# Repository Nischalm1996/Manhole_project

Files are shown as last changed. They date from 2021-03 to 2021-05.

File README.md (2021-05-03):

# Manhole_project

## Pin Connection from Board 
| Pin Name  | Digital Pin |
|---|---|
|SCK | D13 |
| MOSI | D11 |
| OK | D6 |
| LEFT | D10 |
| RIGHT | D8 |
| RST | D12 |
| RED | D0 |
| GREEN | A6 |
| BLUE | A7 |
| MQ2 | A2 |
| MQ7 | A3 |
| MQ06 | A1 |
| MQ135 | A0 |

### MODULES USED
- DISPLAY 16x2 I2C
- SMOKE SENSOR (MQ02,MQ06,MQ07,MQ135)
- MQ02 (Methane, Butane, LPG, Hydrogen)
- MQ07 (CO, benzene)
- MQ06 (iso-butane, propane, LPG, LNG)
- MQ135 (NH3, NOx, alcohol,CO2)
- NAVIGATION BUTTON
- RGB LED
- GSM

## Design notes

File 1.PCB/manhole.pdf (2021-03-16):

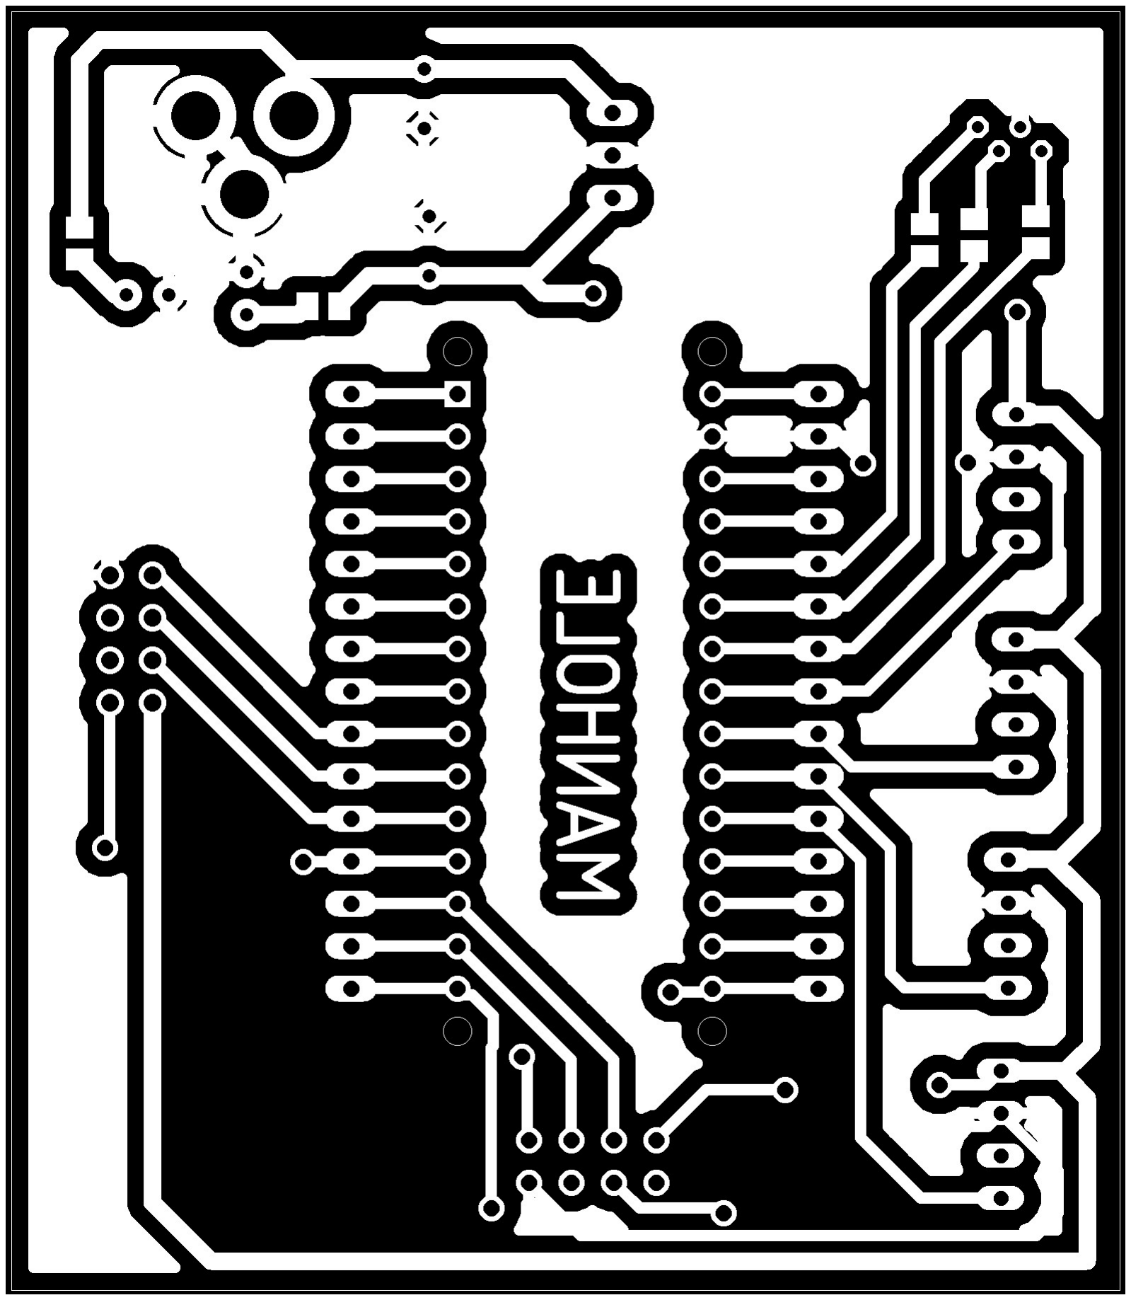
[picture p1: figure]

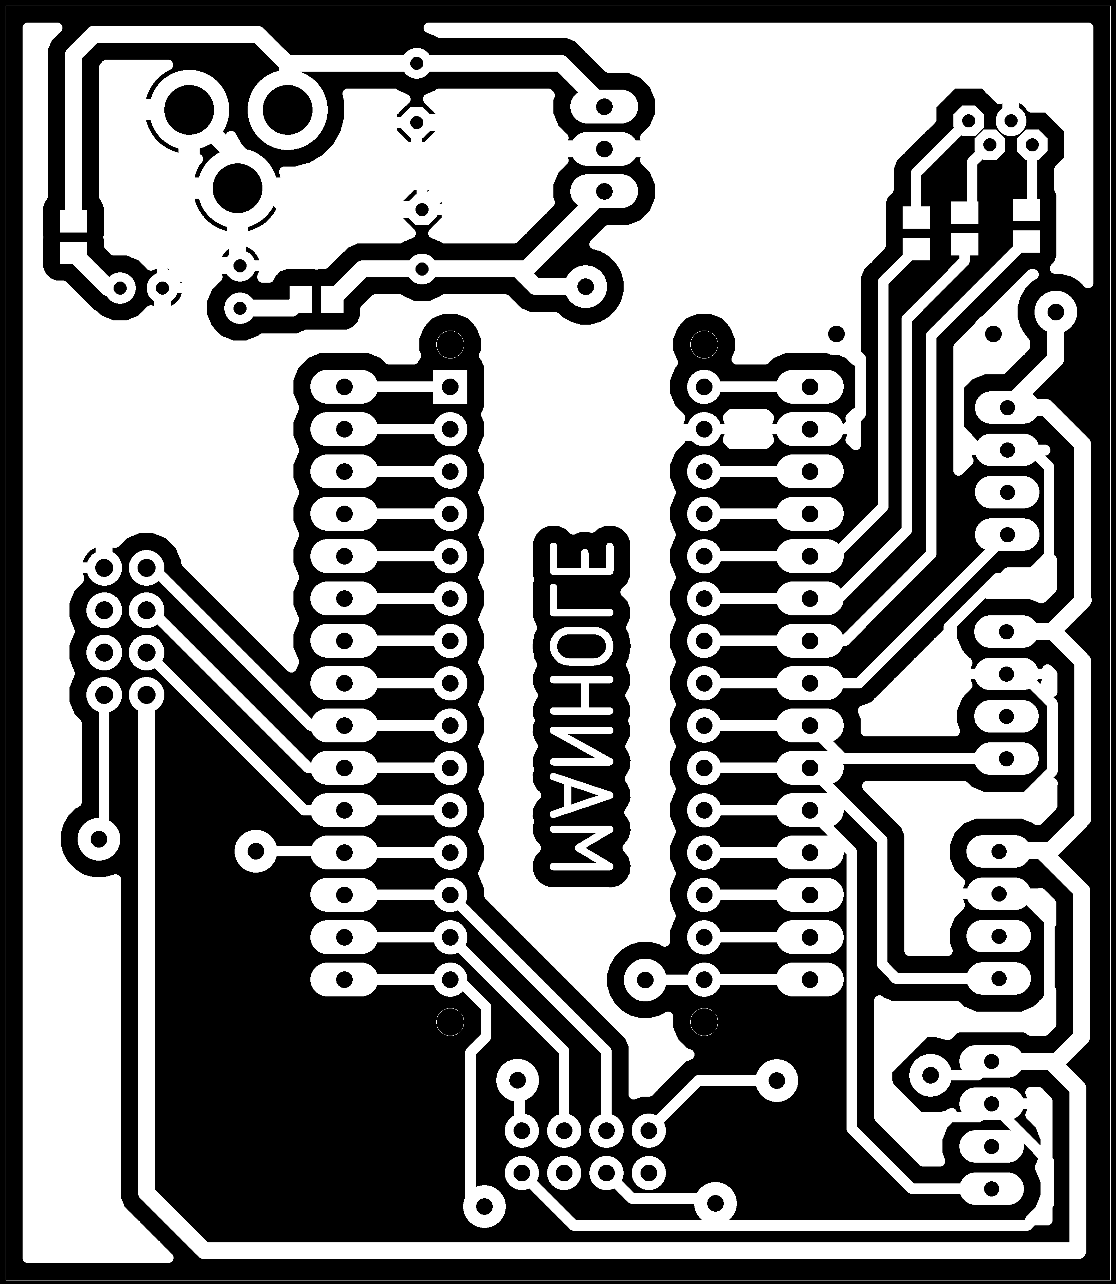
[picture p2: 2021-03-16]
1.PCB/manhole.png

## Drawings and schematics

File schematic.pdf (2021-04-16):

A

A

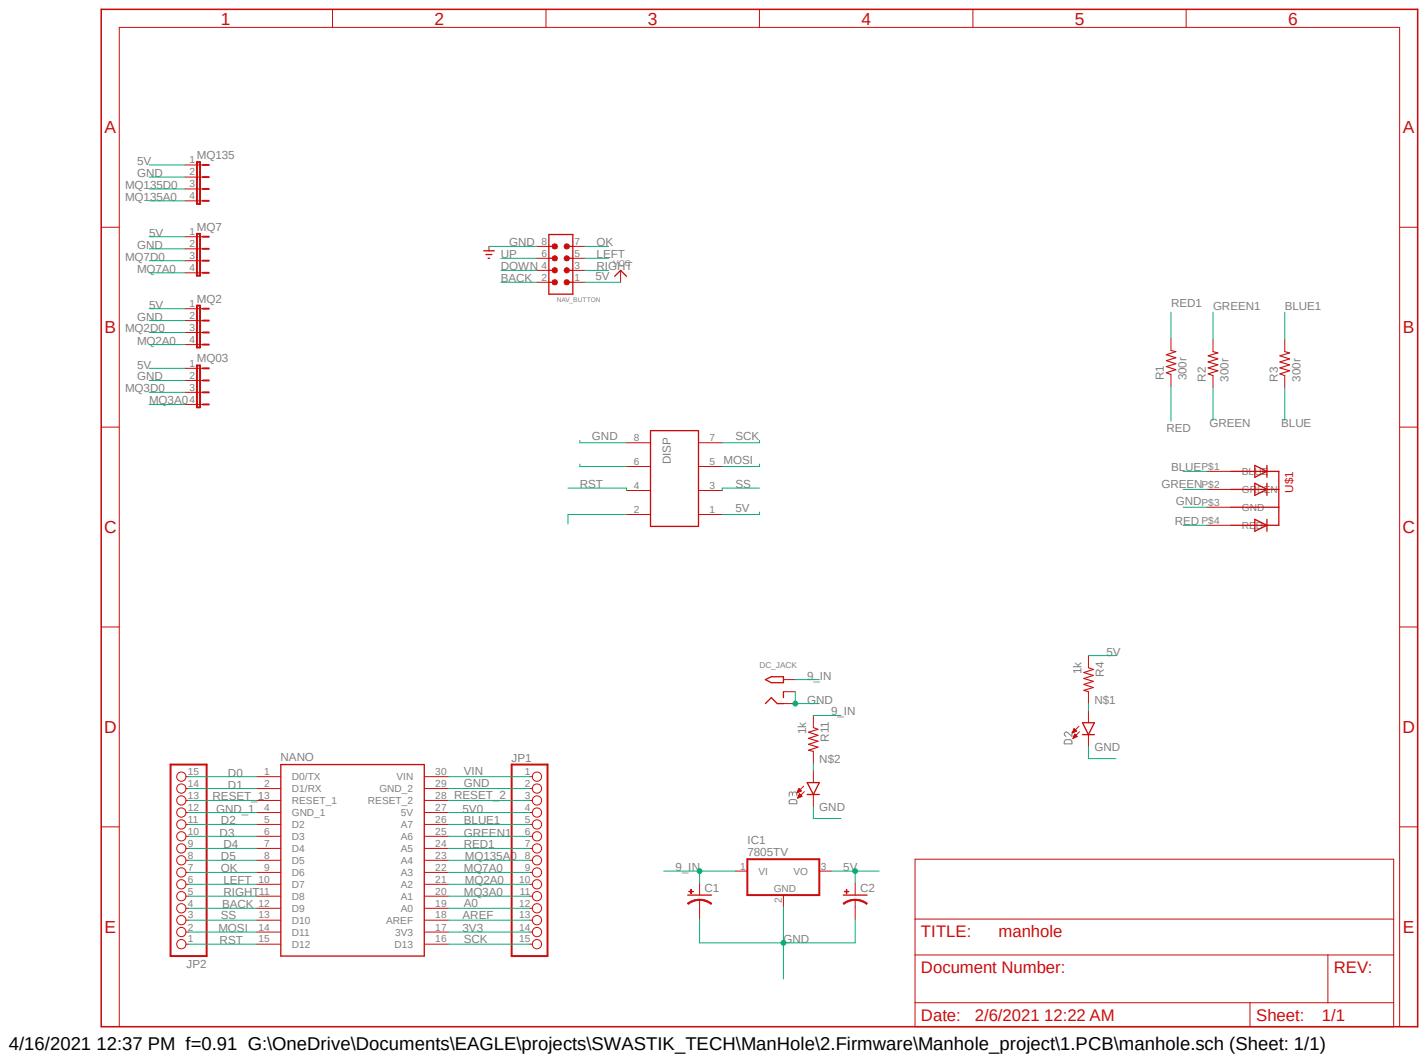
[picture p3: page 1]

Document Number: | REV:

Date: 2/6/2021 12:22 AM | Sheet: 1/1

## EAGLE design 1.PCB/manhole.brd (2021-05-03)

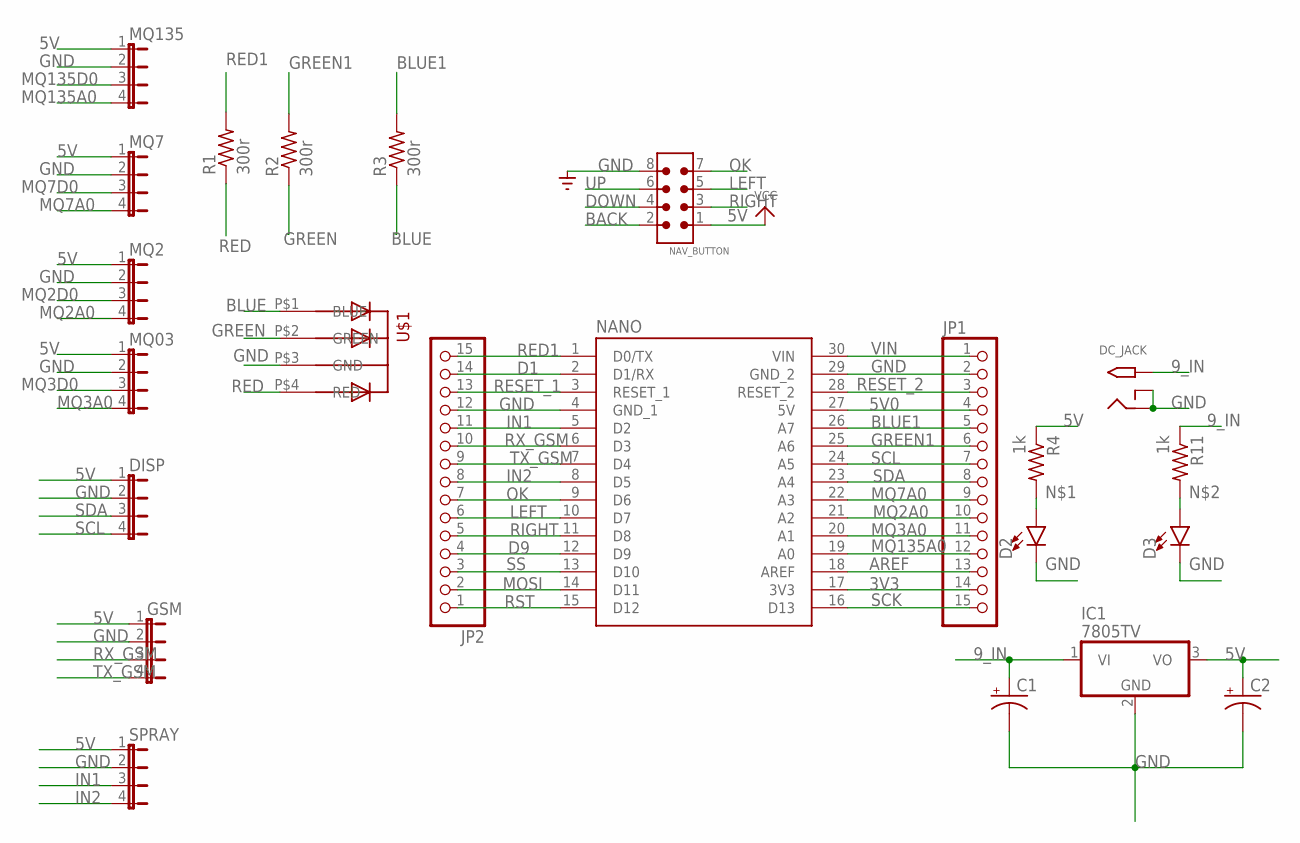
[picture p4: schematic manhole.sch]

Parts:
C1, C2: CPOL-USE3.5-8; E3,5-8
D2, D3: LED3MM; LED_3MM
DC_JACK: 2.1MMJACKTHM; PJ-102A
DISP: JP4E; JP4
GSM: JP4E; JP4
IC1: 7805TV; TO220V
JP1, JP2: PINHD-1X15; 1X15
MQ2, MQ03, MQ7, MQ135: JP4E; JP4
NANO: A000005; MODULE_A000005
NAV_BUTTON: 6120XX21621_61200821621; 61200821621
R1, R2, R3: 300r; M0805
R4, R11: 1k; M0805
SPRAY: JP4E; JP4
U$1: 5MMRGBLED; LED5MMRGB

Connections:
3V3: JP1.14, NANO.17 (3V3)
5V: C2.+, DISP.1, GSM.1, IC1.3 (VO), MQ2.1, MQ03.1, MQ7.1, MQ135.1, NAV_BUTTON.1, R4.1, SPRAY.1
5V0: JP1.4, NANO.27 (5V)
9_IN: C1.+, DC_JACK.TIP, IC1.1 (VI), R11.1
AREF: JP1.13, NANO.18 (AREF)
BACK: NAV_BUTTON.2
BLUE: R3.1, U$1.P$1 (BLUE)
BLUE1: JP1.5, NANO.26 (A7), R3.2
D1: JP2.14, NANO.2 (D1/RX)
D9: JP2.4, NANO.12 (D9)
DOWN: NAV_BUTTON.4
GND: C1.-, C2.-, D2.K (C), D3.K (C), DC_JACK.RING, DC_JACK.RING_SW, DISP.2, GSM.2, IC1.2 (GND), JP1.2, JP2.12, MQ2.2, MQ03.2, MQ7.2, MQ135.2, NANO.4 (GND_1), NANO.29 (GND_2), NAV_BUTTON.8, SPRAY.2, U$1.P$3 (GND)
GREEN: R2.1, U$1.P$2 (GREEN)
GREEN1: JP1.6, NANO.25 (A6), R2.2
IN1: JP2.11, NANO.5 (D2), SPRAY.3
IN2: JP2.8, NANO.8 (D5), SPRAY.4
LEFT: JP2.6, NANO.10 (D7), NAV_BUTTON.5
MOSI: JP2.2, NANO.14 (D11)
MQ2A0: JP1.10, MQ2.4, NANO.21 (A2)
MQ2D0: MQ2.3
MQ3A0: JP1.11, MQ03.4, NANO.20 (A1)
MQ3D0: MQ03.3
MQ7A0: JP1.9, MQ7.4, NANO.22 (A3)
MQ7D0: MQ7.3
MQ135A0: JP1.12, MQ135.4, NANO.19 (A0)
MQ135D0: MQ135.3
unnamed: D2.A, R4.2
unnamed: D3.A, R11.2
OK: JP2.7, NANO.9 (D6), NAV_BUTTON.7
RED: R1.1, U$1.P$4 (RED)
RED1: JP2.15, NANO.1 (D0/TX), R1.2
RESET_1: JP2.13, NANO.3 (RESET_1)
RESET_2: JP1.3, NANO.28 (RESET_2)
RIGHT: JP2.5, NANO.11 (D8), NAV_BUTTON.3
RST: JP2.1, NANO.15 (D12)
RX_GSM: GSM.3, JP2.10, NANO.6 (D3)
SCK: JP1.15, NANO.16 (D13)
SCL: DISP.4, JP1.7, NANO.24 (A5)
SDA: DISP.3, JP1.8, NANO.23 (A4)
SS: JP2.3, NANO.13 (D10)
TX_GSM: GSM.4, JP2.9, NANO.7 (D4)
UP: NAV_BUTTON.6
VIN: JP1.1, NANO.30 (VIN)

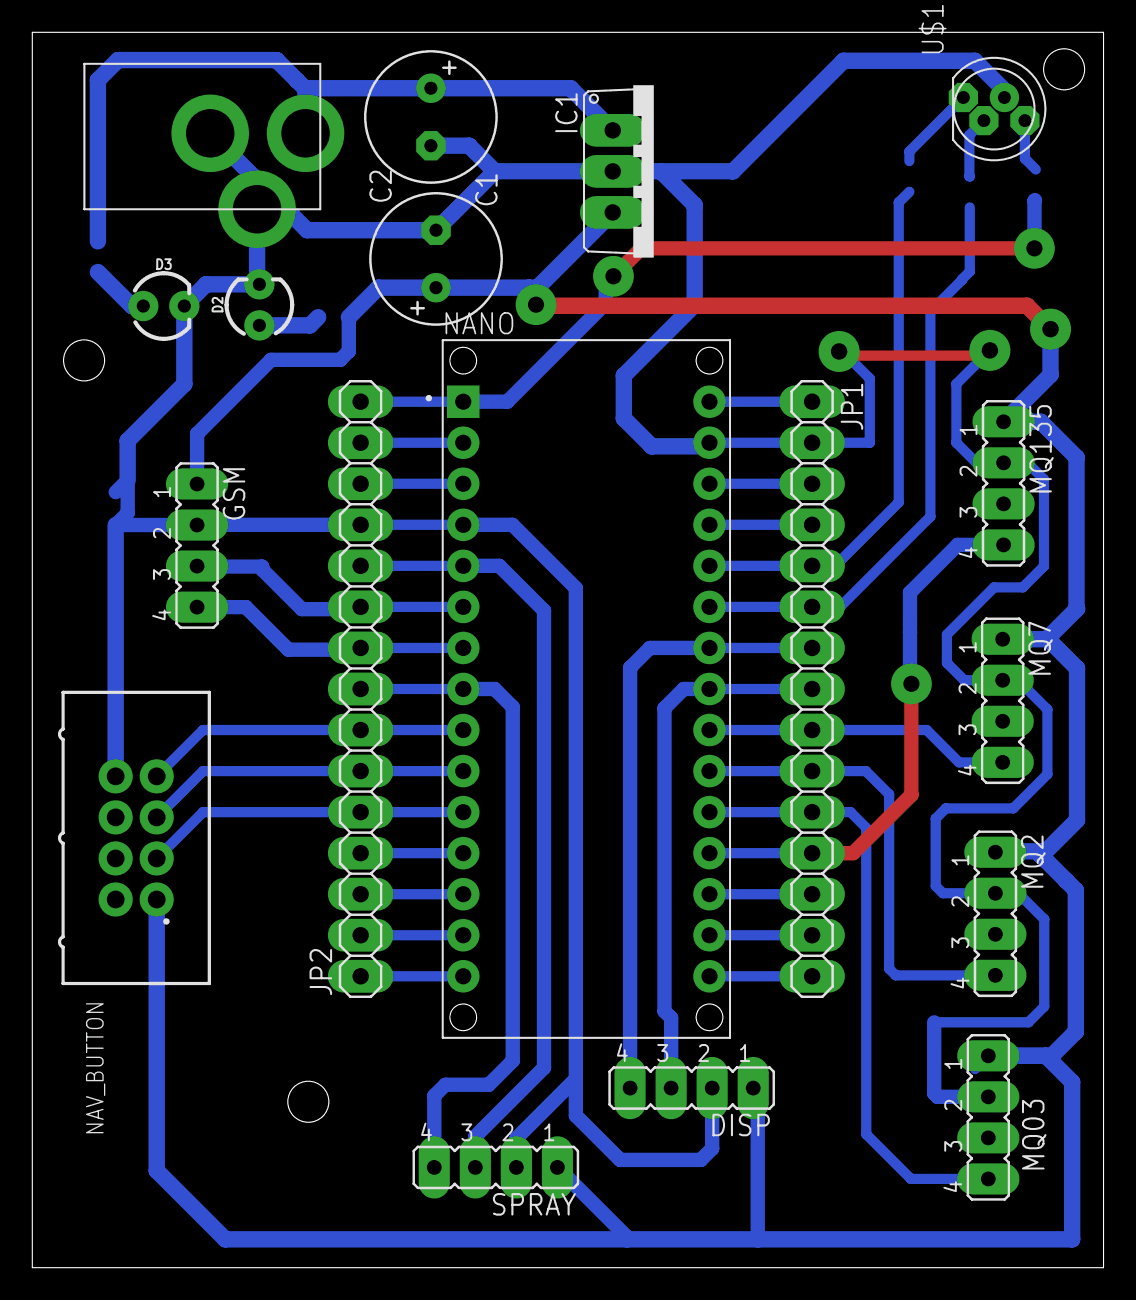
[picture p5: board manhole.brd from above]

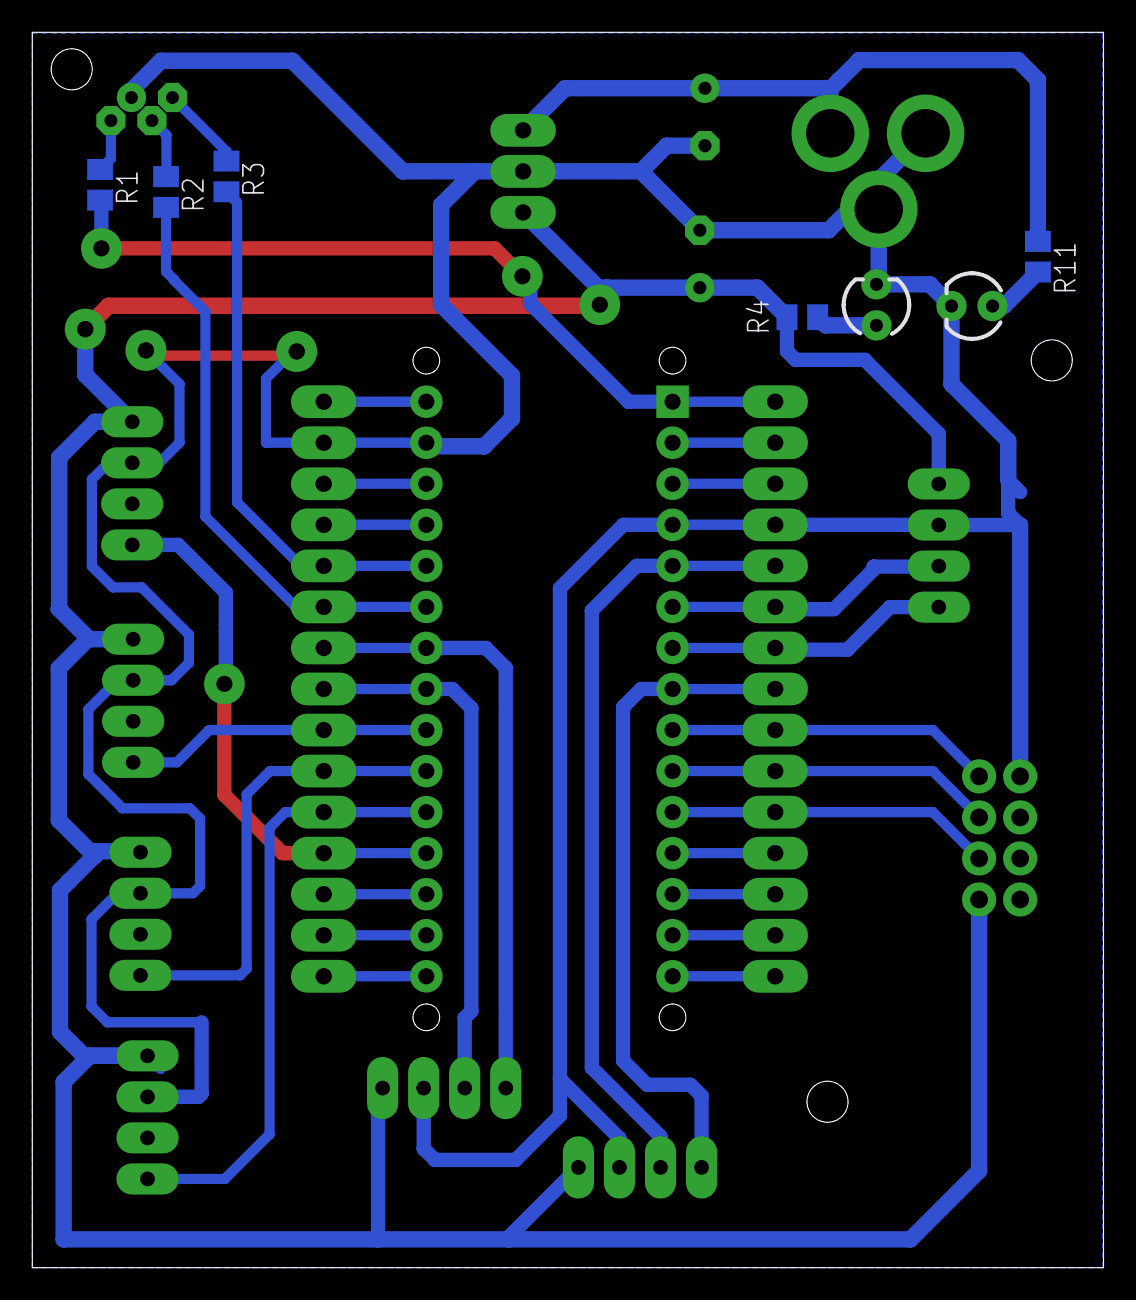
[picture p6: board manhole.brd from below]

Board: 2 copper layers, 66.3 x 76.5 mm, 23 parts (5 on the bottom side), 36 nets.

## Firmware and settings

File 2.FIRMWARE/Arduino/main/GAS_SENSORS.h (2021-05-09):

#ifndef _GAS_SENSOR_H
#define _GAS_SENSOR_H
#include "Arduino.h"
#include <MQUnifiedsensor.h>

/************************Hardware Related Macros************************************/
#define         Board                   ("Arduino Mega")
const int       PMQ135                  =(A0);
const int       PMQ7                    =(A1);
const int       PMQ6                    =(A2);
const int       PMQ2                    =(A3);
/***********************Software Related Macros************************************/
#define         RatioMQ2CleanAir          (9.83) //RS / R0 = 9.83 ppm 
#define         RatioMQ6CleanAir          (10) //RS / R0 = 10 ppm 
#define         RatioMQ7CleanAir          (27.5) //RS / R0 = 27.5 ppm  
#define         RatioMQ135CleanAir        (3.6) //RS / R0 = 9.6 ppm 
#define         ADC_Bit_Resolution        (10) // 10 bit ADC 
#define         Voltage_Resolution        (5) // Volt resolution to calc the voltage
#define         Type                      ("Arduino Nano") //Board used
/*****************************Globals***********************************************/
//Declare Sensor
MQUnifiedsensor MQ135(Board, Voltage_Resolution, ADC_Bit_Resolution, PMQ135, Type);
MQUnifiedsensor MQ2(Board, Voltage_Resolution, ADC_Bit_Resolution, PMQ2, Type);
MQUnifiedsensor MQ6(Board, Voltage_Resolution, ADC_Bit_Resolution, PMQ6, Type);
MQUnifiedsensor MQ7(Board, Voltage_Resolution, ADC_Bit_Resolution, PMQ7, Type);
class GAS_SENSORS
{
  public:
    void begin() {
      //Init serial port
      Serial.begin(9600);
      //init the sensor
      MQ2.init();
      MQ2.setRegressionMethod(1); //_PPM =  a*ratio^b
      MQ2.setA(574.25); MQ2.setB(-2.222); // Configurate the ecuation values to get LPG concentration
      MQ2.setR0(9.659574468);

      MQ6.init();
      MQ6.setRegressionMethod(1); //_PPM =  a*ratio^b
      MQ6.setA(2127.2); MQ6.setB(-2.526); // Configurate the ecuation values to get CH4 concentration
      MQ6.setR0(13.4285714);

      MQ7.init();
      MQ7.setRegressionMethod(1); //_PPM =  a*ratio^b
      MQ7.setA(99.042); MQ7.setB(-1.518); // Configurate the ecuation values to get CO concentration
      MQ7.setR0(4);

      MQ135.init();
      MQ135.setRegressionMethod(1); //_PPM =  a*ratio^b
      MQ135.setA(102.2); MQ135.setB(-2.473);// Configurate the ecuation values to get NH4 concentration
      MQ135.setR0(10);

      /*****************************  MQ CAlibration ********************************************/
      // Explanation:
      // In this routine the sensor will measure the resistance of the sensor supposing before was pre-heated
      // and now is on clean air (Calibration conditions), and it will setup R0 value.
      // We recomend execute this routine only on setup or on the laboratory and save on the eeprom of your arduino
      // This routine not need to execute to every restart, you can load your R0 if you know the value
      // Acknowledgements: https://jayconsystems.com/blog/understanding-a-gas-sensor
      Serial.print(F("Calibrating please wait."));
      float MQ2calcR0 = 0,
            MQ6calcR0 = 0,
            MQ7calcR0 = 0,
            MQ135calcR0 = 0;
      for (int i = 1; i <= 10; i ++)
      {
        //Update the voltage lectures
        MQ2.update();
        MQ6.update();
        MQ7.update();
        MQ135.update();

        MQ2calcR0 += MQ2.calibrate(RatioMQ2CleanAir);
        MQ6calcR0 += MQ2.calibrate(RatioMQ6CleanAir);
        MQ7calcR0 += MQ2.calibrate(RatioMQ7CleanAir);
        MQ135calcR0 += MQ2.calibrate(RatioMQ135CleanAir);
        Serial.print(F("."));
      }
      MQ2.setR0(MQ2calcR0 / 20);
      MQ6.setR0(MQ6calcR0 / 20);
      MQ7.setR0(MQ7calcR0 / 20);
      MQ135.setR0(MQ135calcR0 / 20);
      

      if (isinf(MQ2calcR0) || isinf(MQ6calcR0) || isinf(MQ7calcR0) || isinf(MQ135calcR0)) {
        Serial.println(F("Warning: Conection issue founded, R0 is infite (Open circuit detected) please check your wiring and supply"));
        while (1);
      }
      if (MQ2calcR0 == 0 || MQ6calcR0 == 0 || MQ7calcR0 == 0 || MQ135calcR0 == 0) {
        Serial.println(F("Warning: Conection issue founded, R0 is zero (Analog pin with short circuit to ground) please check your wiring and supply"));
        while (1);
      }
      /*****************************  MQ CAlibration ********************************************/
    }

    float getLpgPPM()
    {
      MQ2.update();
      return (MQ2.readSensor());
    }
    float getMethanePPM()
    {
      MQ6.update();
      return (MQ6.readSensor());
    }
    float getCoPPM()
    {
      MQ7.update();
      return (MQ7.readSensor());
    }
    float getAmmoniaPPM()
    {
      MQ135.update();
      return (MQ135.readSensor());
    }

};
#endif

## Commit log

2021-03-16 added PCB
    [manhole.brd, manhole.sch]
2021-03-16 PCB added
    [manhole.brd]
2021-04-16 added schematic
    [manhole.brd, manhole.sch]
2021-04-16 updated structure
    [manhole.brd, manhole.sch]
2021-04-17 SENSOR-MQ03,02,07,135 codes dumped
2021-04-17 added rgb led
2021-04-20 sensor pin updates
2021-04-21 MQ sensors gas detections
2021-04-28 edited button menu and gsm
2021-05-03 removed mq03 sensor
2021-05-04 updated PCB
    [manhole.brd]
2021-05-09 Revert "updated PCB"
    This reverts commit e032bd37680646525048ee8d74092bea044d5abf.
    [manhole.brd, manhole.sch]

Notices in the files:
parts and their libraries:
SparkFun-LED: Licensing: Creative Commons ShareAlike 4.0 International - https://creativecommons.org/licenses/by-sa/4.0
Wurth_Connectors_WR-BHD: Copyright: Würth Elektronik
